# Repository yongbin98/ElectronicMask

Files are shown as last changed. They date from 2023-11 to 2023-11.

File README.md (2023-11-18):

# ElectronicMask
The code is for the assignment "Developing breathing-based vital signs detection models and control algorithms to improve sleep quality" <br>

# Sensors
`MCU` : STM32F765VI <br>
`Bluetooth` : E104-BT5005A <br>
`Pressure Sensor` : LPS22HHTR <br>
`Microphone` : SPH0645LM4H-1-8 <br>
`IMU Sensor` : LSM6DSMTR <br>
`PPG Sensor` : MAX86171 & SFH 7072 <br>
`EMG EOG EEG sensor` : ADS1299 <br>

# Developed ElectronicMask (Prototype)


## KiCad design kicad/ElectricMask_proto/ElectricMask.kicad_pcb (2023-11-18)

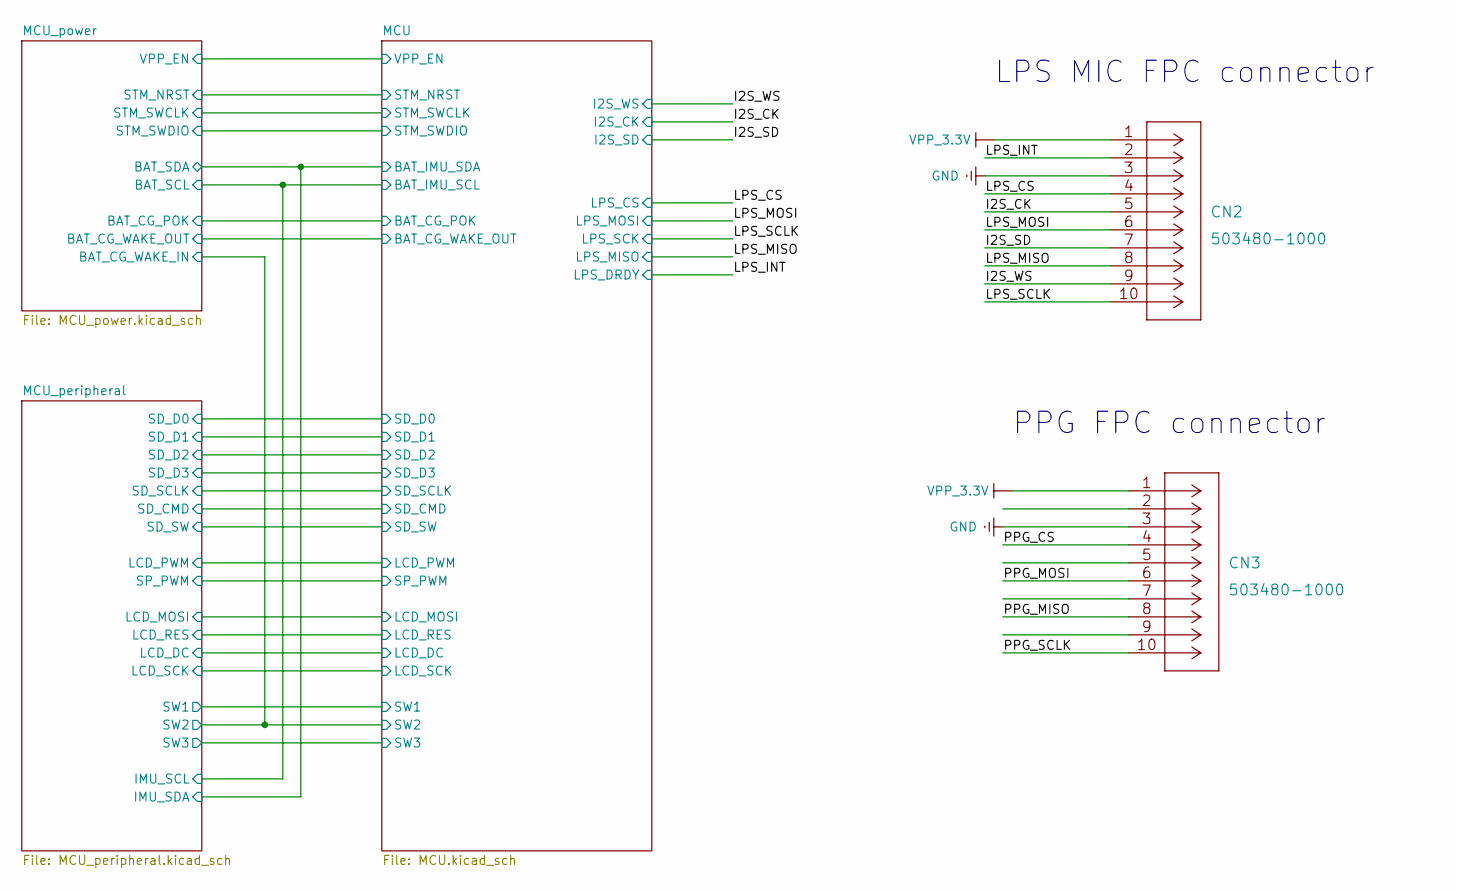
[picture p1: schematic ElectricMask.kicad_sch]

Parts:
CN2, CN3: 503480-1000

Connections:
/I2S_CK: CN2.5; also elsewhere on the board
/I2S_SD: CN2.7; also elsewhere on the board
/I2S_WS: CN2.9; also elsewhere on the board
/LPS_CS: CN2.4; also elsewhere on the board
/LPS_INT: CN2.2; also elsewhere on the board
/LPS_MISO: CN2.8; also elsewhere on the board
/LPS_MOSI: CN2.6; also elsewhere on the board
/LPS_SCLK: CN2.10; also elsewhere on the board

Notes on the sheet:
PPG FPC connector
LPS MIC FPC connector

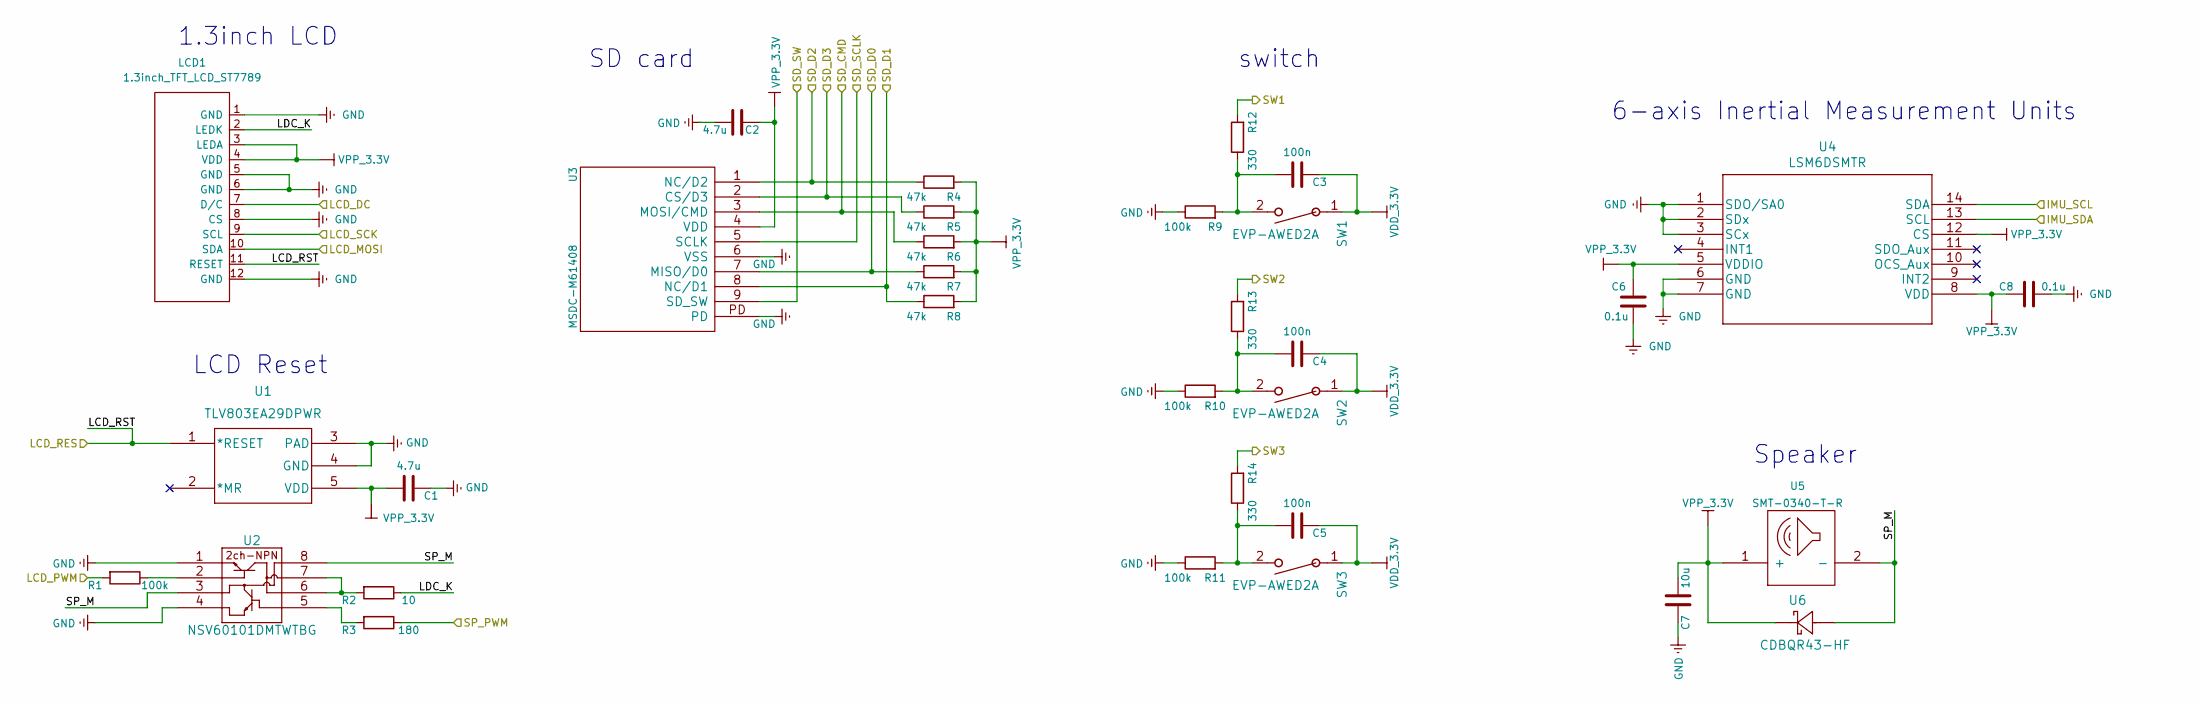
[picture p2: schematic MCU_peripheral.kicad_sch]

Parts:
C1, C2: 4.7u; UL_C_0402_1005Metric
C3, C4, C5: 100n; UL_C_0402_1005Metric
C6, C8: 0.1u; UL_C_0402_1005Metric
C7: 10u; UL_C_0402_1005Metric
LCD1: 1.3inch_TFT_LCD_ST7789
R1, R9, R10, R11: 100k; R_0402_1005Metric
R2: 10; R_0402_1005Metric
R3: 180; R_0402_1005Metric
R4, R5, R6, R7, R8: 47k; R_0402_1005Metric
R12, R13, R14: 330; R_0402_1005Metric
SW1, SW2, SW3: EVP-AWED2A
U1: TLV803EA29DPWR
U2: NSV60101DMTWTBG
U3: MSDC-M61408; MSDC-M61408(Micro_SD)
U4: LSM6DSMTR
U5: SMT-0340-T-R
U6: CDBQR43-HF

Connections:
/MCU/BAT_IMU_SCL: U4.14 (SDA); also elsewhere on the board
/MCU/BAT_IMU_SDA: U4.13 (SCL); also elsewhere on the board
/MCU/LCD_DC: LCD1.7 (D/C); also elsewhere on the board
/MCU/LCD_MOSI: LCD1.10 (SDA); also elsewhere on the board
/MCU/LCD_PWM: R1.2; also elsewhere on the board
/MCU/LCD_SCK: LCD1.9 (SCL); also elsewhere on the board
/MCU/SD_CMD: R6.1, U3.3 (MOSI/CMD); also elsewhere on the board
/MCU/SD_D0: R7.1, U3.7 (MISO/D0); also elsewhere on the board
/MCU/SD_D1: R8.1, U3.8 (NC/D1); also elsewhere on the board
/MCU/SD_D2: R4.1, U3.1 (NC/D2); also elsewhere on the board
/MCU/SD_D3: R5.1, U3.2 (CS/D3); also elsewhere on the board
/MCU/SD_SCLK: U3.5 (SCLK); also elsewhere on the board
/MCU/SD_SW: U3.9 (SD_SW); also elsewhere on the board
/MCU/SP_PWM: R3.1; also elsewhere on the board
/MCU/SW1: R12.2; also elsewhere on the board
/MCU/SW2: R13.2; also elsewhere on the board
/MCU/SW3: R14.2; also elsewhere on the board
/MCU_peripheral/LCD_RST: LCD1.11 (RESET), U1.1 (*RESET); also elsewhere on the board
/MCU_peripheral/LDC_K: LCD1.2 (LEDK), R2.1
/MCU_peripheral/SP_M: U2.3, U2.8, U5.2 (-), U6.2
unnamed: C3.2, R9.2, R12.1, SW1.2
unnamed: C4.2, R10.2, R13.1, SW2.2
unnamed: C5.2, R11.2, R14.1, SW3.2
unnamed: R1.1, U2.2
unnamed: R2.2, U2.6, U2.7
unnamed: R3.2, U2.5
VDD_3_3V: C3.1, C4.1, C5.1, SW1.1, SW2.1, SW3.1; also elsewhere on the board

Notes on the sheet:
Speaker
6-axis Inertial Measurement Units
LCD Reset
SD card
1.3inch LCD
switch

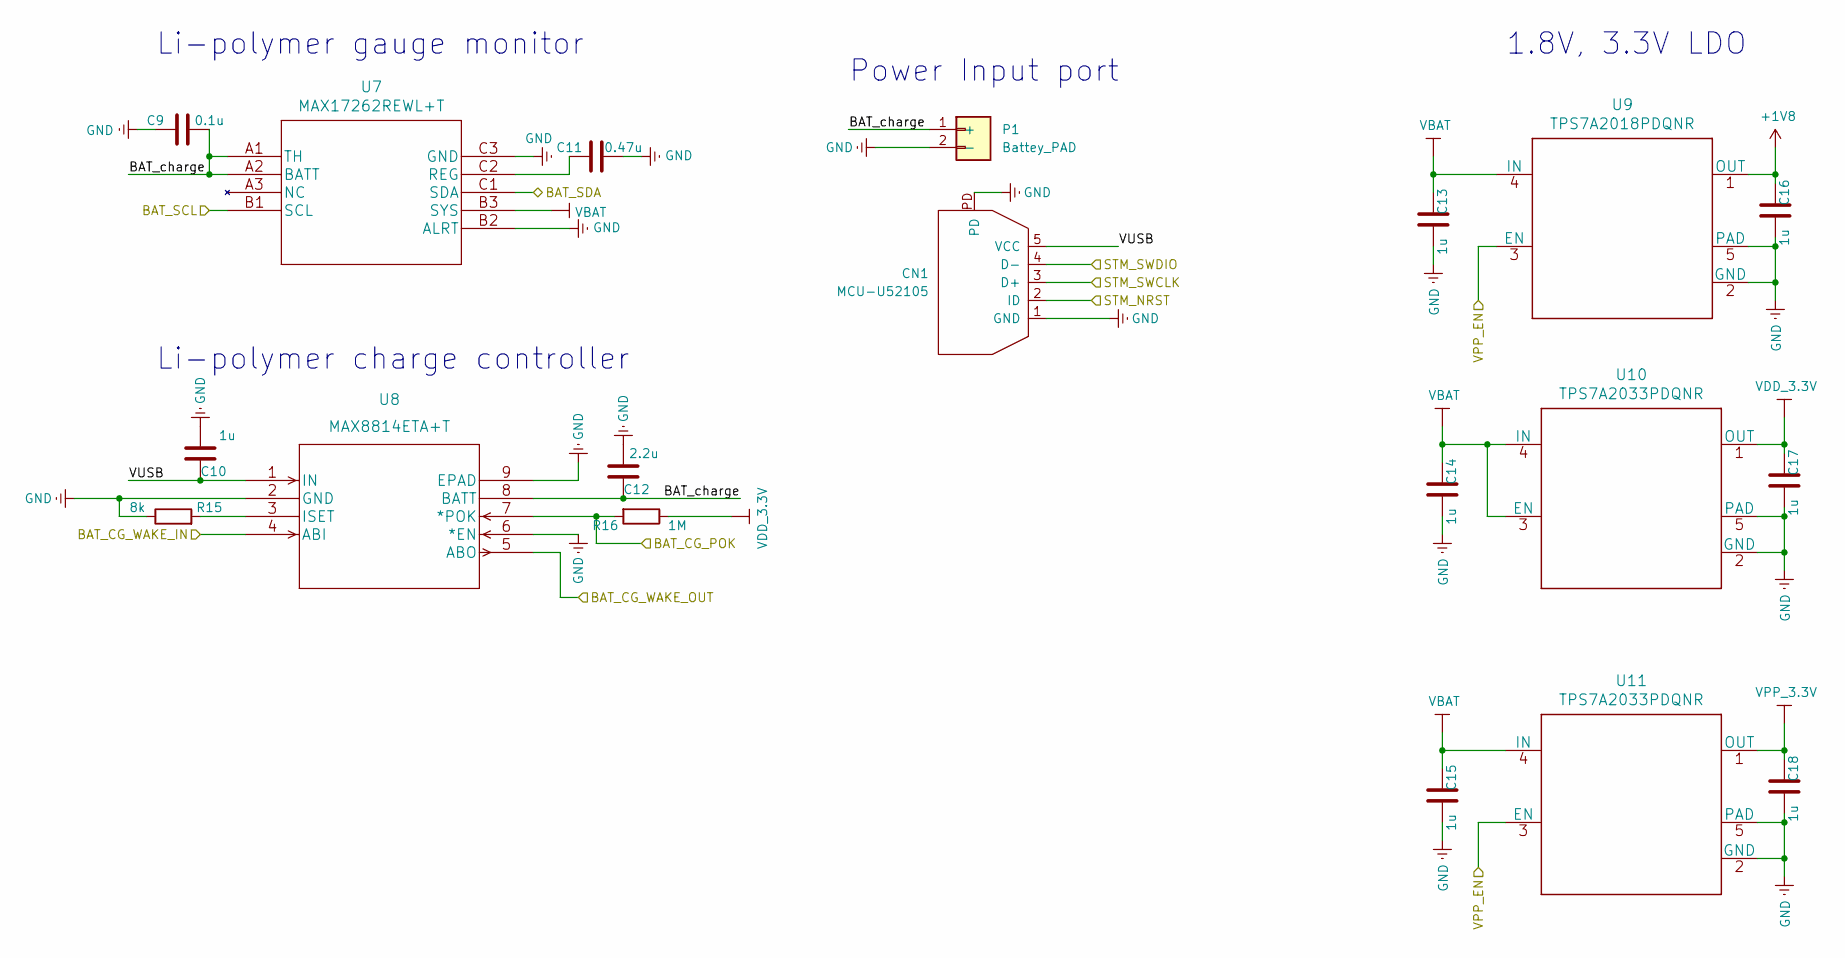
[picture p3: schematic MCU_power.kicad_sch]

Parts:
C9: 0.1u; UL_C_0402_1005Metric
C10, C13, C14, C15, C16, C17, C18: 1u; UL_C_0402_1005Metric
C11: 0.47u; UL_C_0402_1005Metric
C12: 2.2u; UL_C_0402_1005Metric
CN1: MCU-U52105
P1: Battey_PAD
R15: 8k; R_0402_1005Metric
R16: 1M; R_0402_1005Metric
U7: MAX17262REWL+T; MAX17262REWL&plus_T
U8: MAX8814ETA+T; MAX8814ETA&plus_T
U9: TPS7A2018PDQNR; X2SON-4PIN
U10, U11: TPS7A2033PDQNR; X2SON-4PIN

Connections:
+1V8: C16.2, U9.1 (OUT)
/MCU/BAT_CG_POK: R16.2, U8.7 (*POK); also elsewhere on the board
/MCU/BAT_CG_WAKE_OUT: U8.5 (ABO); also elsewhere on the board
/MCU/BAT_IMU_SCL: U7.B1 (SCL); also elsewhere on the board
/MCU/BAT_IMU_SDA: U7.C1 (SDA); also elsewhere on the board
/MCU/STM_NRST: CN1.2 (ID); also elsewhere on the board
/MCU/STM_SWCLK: CN1.3 (D+); also elsewhere on the board
/MCU/STM_SWDIO: CN1.4 (D-); also elsewhere on the board
/MCU/SW2: U8.4 (ABI); also elsewhere on the board
/MCU/VPP_EN: U9.3 (EN), U11.3 (EN); also elsewhere on the board
/MCU_power/BAT_charge: C9.2, C12.1, P1.1 (+), U7.A1 (TH), U7.A2 (BATT), U8.8 (BATT)
/MCU_power/VUSB: C10.1, CN1.5 (VCC), U8.1 (IN)
unnamed: C11.2, U7.C2 (REG)
unnamed: R15.2, U8.3 (ISET)
VBAT: C13.2, C14.2, C15.2, U7.B3 (SYS), U9.4 (IN), U10.3 (EN), U10.4 (IN), U11.4 (IN)
VDD_3_3V: C17.2, R16.1, U10.1 (OUT); also elsewhere on the board

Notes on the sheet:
Power Input port
Li-polymer gauge monitor
1.8V, 3.3V LDO
Li-polymer charge controller

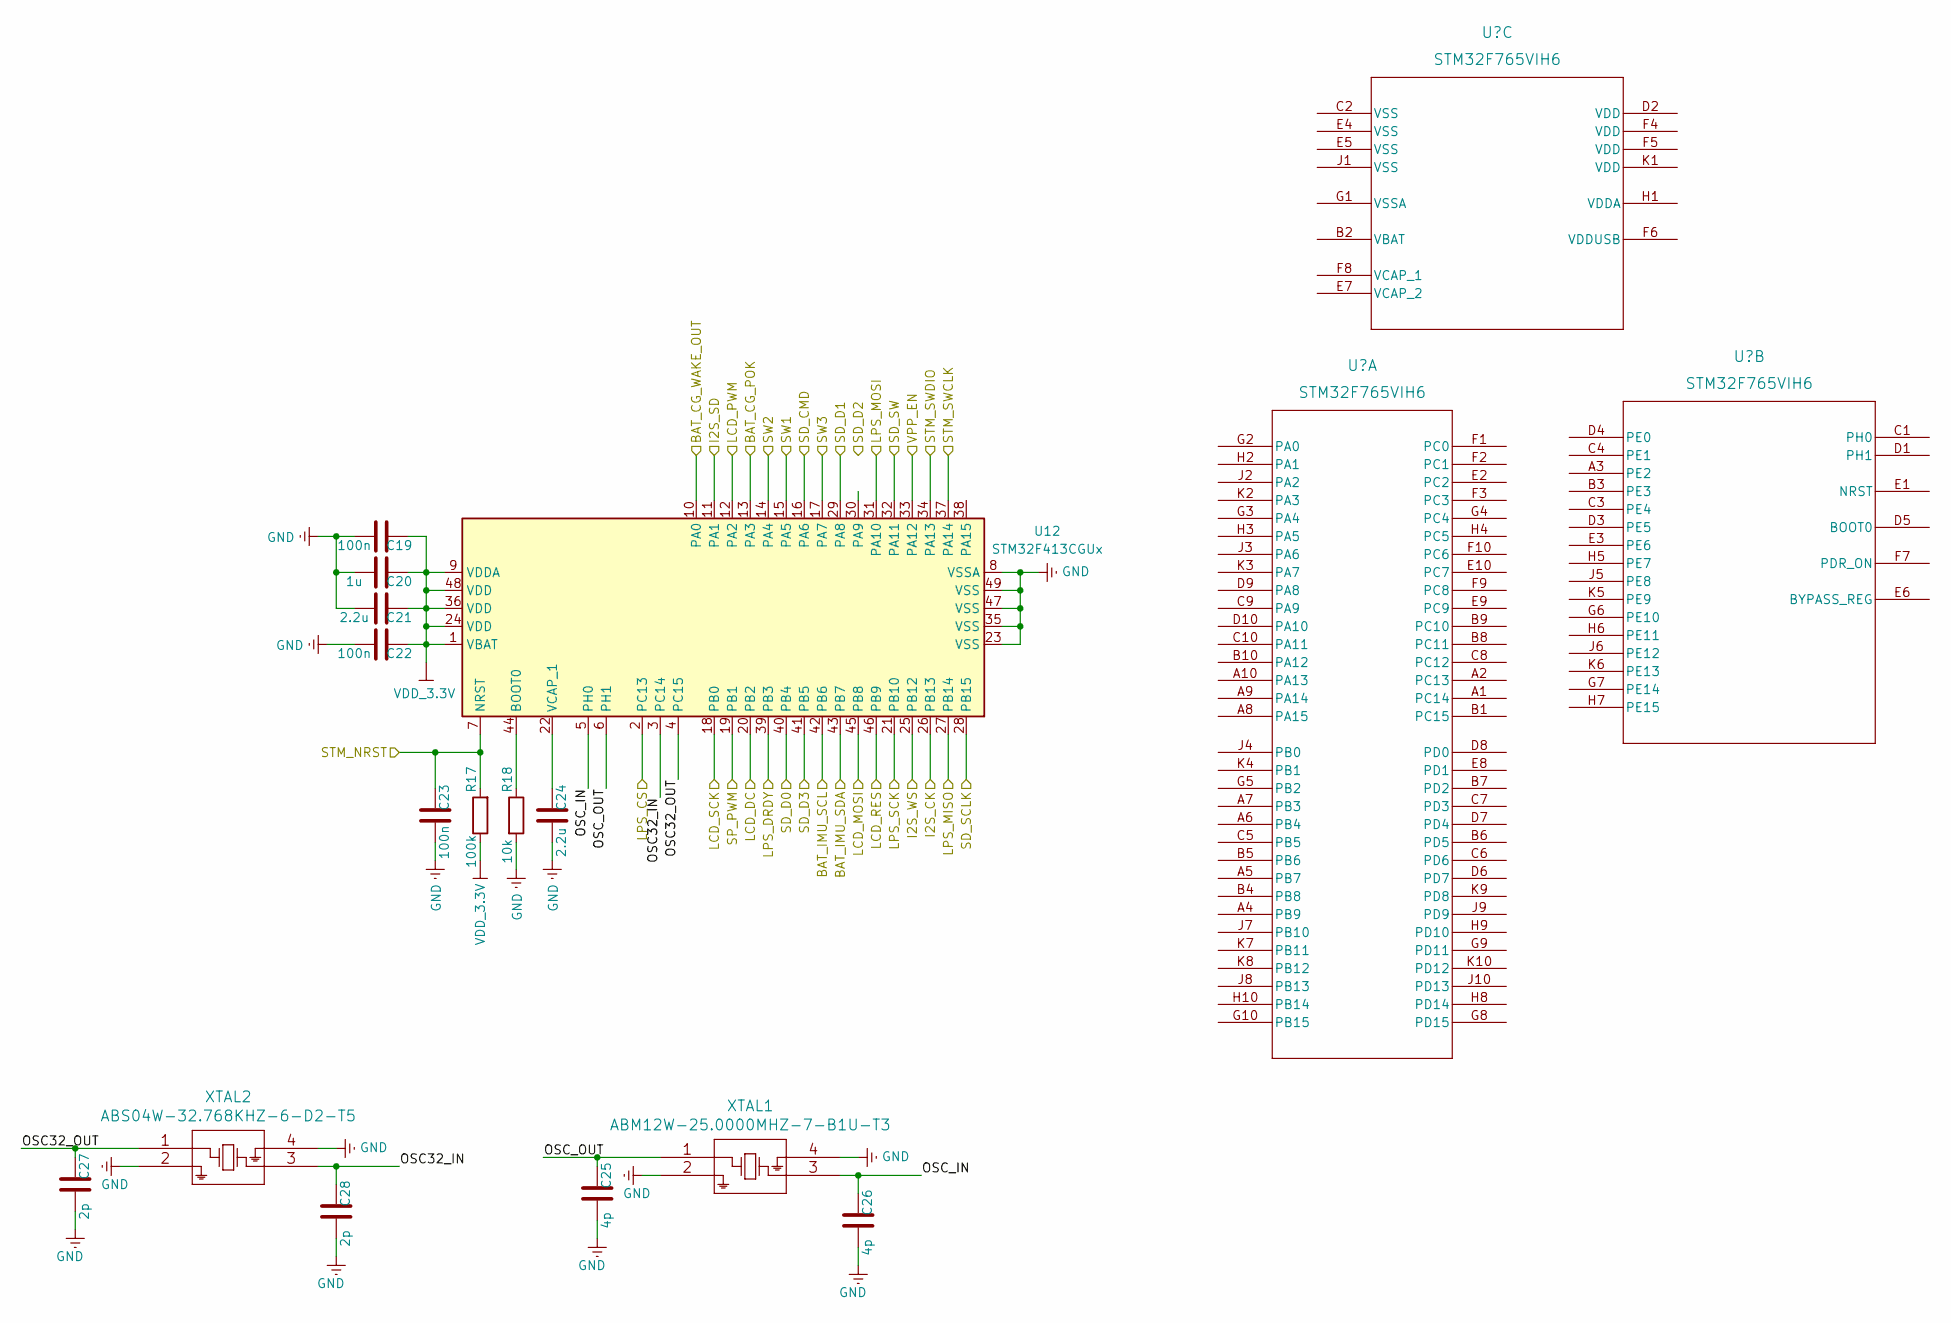
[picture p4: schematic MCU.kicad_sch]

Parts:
C19, C22, C23: 100n; UL_C_0402_1005Metric
C20: 1u; UL_C_0402_1005Metric
C21, C24: 2.2u; UL_C_0402_1005Metric
C25, C26: 4p; UL_C_0402_1005Metric
C27, C28: 2p; UL_C_0402_1005Metric
R17: 100k; R_0402_1005Metric
R18: 10k; R_0402_1005Metric
U12: STM32F413CGUx; QFN-48-1EP_7x7mm_P0.5mm_EP5.6x5.6mm
XTAL1: ABM12W-25.0000MHZ-7-B1U-T3; ABM12W
XTAL2: ABS04W-32.768KHZ-6-D2-T5; ABS04W

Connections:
/I2S_CK: U12.26 (PB13); also elsewhere on the board
/I2S_SD: U12.11 (PA1); also elsewhere on the board
/I2S_WS: U12.25 (PB12); also elsewhere on the board
/LPS_CS: U12.2 (PC13); also elsewhere on the board
/LPS_INT: U12.39 (PB3); also elsewhere on the board
/LPS_MISO: U12.27 (PB14); also elsewhere on the board
/LPS_MOSI: U12.31 (PA10); also elsewhere on the board
/LPS_SCLK: U12.21 (PB10); also elsewhere on the board
/MCU/BAT_CG_POK: U12.13 (PA3); also elsewhere on the board
/MCU/BAT_CG_WAKE_OUT: U12.10 (PA0); also elsewhere on the board
/MCU/BAT_IMU_SCL: U12.42 (PB6); also elsewhere on the board
/MCU/BAT_IMU_SDA: U12.43 (PB7); also elsewhere on the board
/MCU/LCD_DC: U12.20 (PB2); also elsewhere on the board
/MCU/LCD_MOSI: U12.45 (PB8); also elsewhere on the board
/MCU/LCD_PWM: U12.12 (PA2); also elsewhere on the board
/MCU/LCD_SCK: U12.18 (PB0); also elsewhere on the board
/MCU/OSC32_IN: C28.2, U12.3 (PC14), XTAL2.3
/MCU/OSC32_OUT: C27.2, U12.4 (PC15), XTAL2.1
/MCU/OSC_IN: C26.2, U12.5 (PH0), XTAL1.3
/MCU/OSC_OUT: C25.2, U12.6 (PH1), XTAL1.1
/MCU/SD_CMD: U12.16 (PA6); also elsewhere on the board
/MCU/SD_D0: U12.40 (PB4); also elsewhere on the board
/MCU/SD_D1: U12.29 (PA8); also elsewhere on the board
/MCU/SD_D2: U12.30 (PA9); also elsewhere on the board
/MCU/SD_D3: U12.41 (PB5); also elsewhere on the board
/MCU/SD_SCLK: U12.28 (PB15); also elsewhere on the board
/MCU/SD_SW: U12.32 (PA11); also elsewhere on the board
/MCU/SP_PWM: U12.19 (PB1); also elsewhere on the board
/MCU/STM_NRST: C23.2, R17.2, U12.7 (NRST); also elsewhere on the board
/MCU/STM_SWCLK: U12.37 (PA14); also elsewhere on the board
/MCU/STM_SWDIO: U12.34 (PA13); also elsewhere on the board
/MCU/SW1: U12.15 (PA5); also elsewhere on the board
/MCU/SW2: U12.14 (PA4); also elsewhere on the board
/MCU/SW3: U12.17 (PA7); also elsewhere on the board
/MCU/VPP_EN: U12.33 (PA12); also elsewhere on the board
/MCU_peripheral/LCD_RST: U12.46 (PB9); also elsewhere on the board
unnamed: C24.2, U12.22 (VCAP_1)
unnamed: R18.1, U12.44 (BOOT0)
VDD_3_3V: C19.2, C20.2, C21.2, C22.2, R17.1, U12.1 (VBAT), U12.9 (VDDA), U12.24 (VDD), U12.36 (VDD), U12.48 (VDD); also elsewhere on the board

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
Board: 2 copper layers, 67 parts (0 on the bottom side), 57 nets, no tracks yet.

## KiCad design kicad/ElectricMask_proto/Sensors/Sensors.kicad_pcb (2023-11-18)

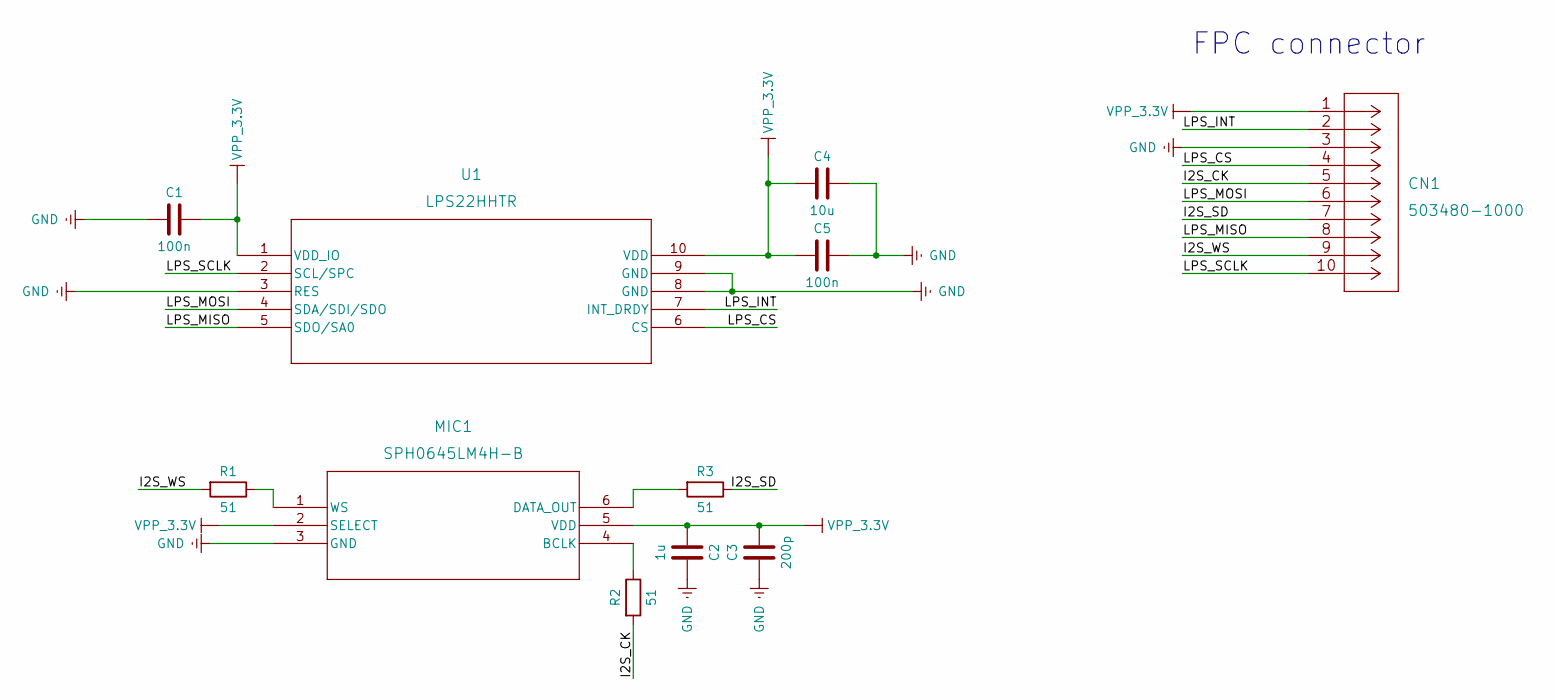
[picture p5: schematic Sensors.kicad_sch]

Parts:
C1, C5: 100n; UL_C_0402_1005Metric
C2: 1u; UL_C_0402_1005Metric
C3: 200p; UL_C_0402_1005Metric
C4: 10u; UL_C_0402_1005Metric
CN1: 503480-1000
MIC1: SPH0645LM4H-B; SPH0645LM4H-B_KNO
R1, R2, R3: 51; R_0402_1005Metric
U1: LPS22HHTR; HLGA-10L_2X2X0P73_STM

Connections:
/I2S_CK: CN1.5, R2.2
/I2S_SD: CN1.7, R3.1
/I2S_WS: CN1.9, R1.2
/LPS_CS: CN1.4, U1.6 (CS)
/LPS_INT: CN1.2, U1.7 (INT_DRDY)
/LPS_MISO: CN1.8, U1.5 (SDO/SA0)
/LPS_MOSI: CN1.6, U1.4 (SDA/SDI/SDO)
/LPS_SCLK: CN1.10, U1.2 (SCL/SPC)
unnamed: MIC1.1 (WS), R1.1
unnamed: MIC1.4 (BCLK), R2.1
unnamed: MIC1.6 (DATA_OUT), R3.2
U_GND: C1.1, C2.2, C3.1, C4.2, C5.2, CN1.3, CN1.11, CN1.12, MIC1.3 (GND), U1.3 (RES), U1.8 (GND), U1.9 (GND)
VDD: C1.2, C2.1, C3.2, C4.1, C5.1, CN1.1, MIC1.2 (SELECT), MIC1.5 (VDD), U1.1 (VDD_IO), U1.10 (VDD)

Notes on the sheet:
FPC connector

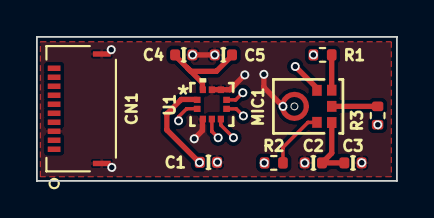
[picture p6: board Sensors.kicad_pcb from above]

Board: 4 copper layers, 20.0 x 8.0 mm, 11 parts (0 on the bottom side), 13 nets.

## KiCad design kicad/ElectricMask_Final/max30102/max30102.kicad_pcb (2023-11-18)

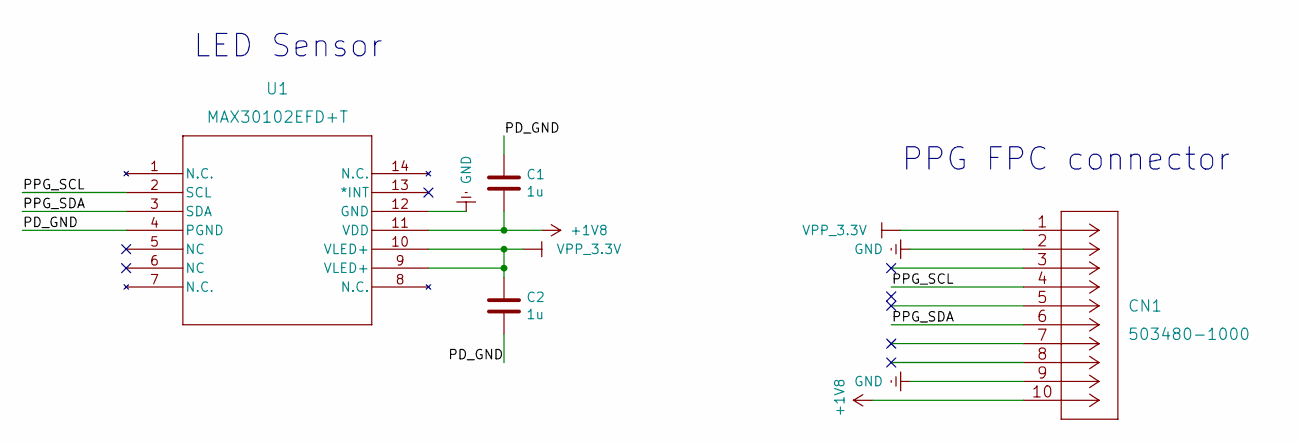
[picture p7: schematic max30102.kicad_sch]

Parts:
C1, C2: 1u; UL_C_0402_1005Metric
CN1: 503480-1000
U1: MAX30102EFD+T; MAX30102

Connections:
+1V8: C1.2, CN1.10, U1.11 (VDD)
/PD_GND: C1.1, C2.2, U1.4 (PGND)
/PPG_SCL: CN1.4, U1.2 (SCL)
/PPG_SDA: CN1.6, U1.3 (SDA)
U_GND: CN1.2, CN1.9, CN1.11, CN1.12, U1.12 (GND)
VPP_3_3V: C2.1, CN1.1, U1.9 (VLED+), U1.10 (VLED+)

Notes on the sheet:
LED Sensor
PPG FPC connector

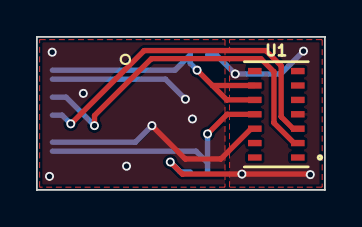
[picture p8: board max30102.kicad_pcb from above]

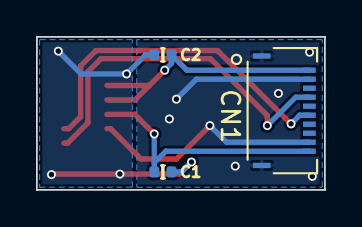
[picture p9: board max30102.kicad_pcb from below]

Board: 2 copper layers, 16.0 x 8.5 mm, 4 parts (3 on the bottom side), 6 nets.

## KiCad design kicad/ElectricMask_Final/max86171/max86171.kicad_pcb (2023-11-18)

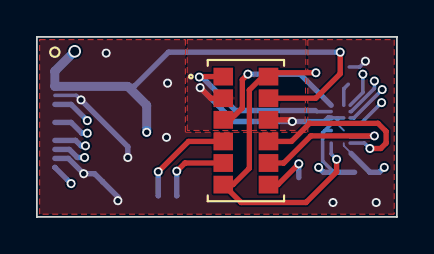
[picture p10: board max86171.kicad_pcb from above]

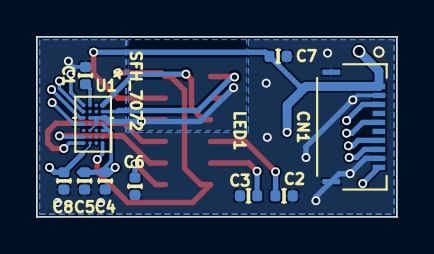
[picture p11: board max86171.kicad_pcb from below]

Board: 4 copper layers, 20.0 x 10.0 mm, 11 parts (10 on the bottom side), 13 nets.

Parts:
C1: 1u; UL_C_0402_1005Metric
C2, C3, C6, C7: 22u; UL_C_0402_1005Metric
C4, C8: 10u; UL_C_0402_1005Metric
C5: 0.1u; UL_C_0402_1005Metric
CN1: 503480-1000
LED1: SFH_7072; SFH 7072
U1: MAX86171ENI+; MAX86171ENI&plus_

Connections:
+1V8: C4.1, C5.1, CN1.10, U1.D3 (VDD_ANA), U1.D4 (VDD_DIG)
/LED3_DRV: LED1.9, U1.A1 (LED3_DRV)
/LED4_DRV: LED1.6, LED1.12, U1.D1 (LED4_DRV)
/LED9_DRV: LED1.8, U1.A2 (LED9_DRV)
/PD1_IN: LED1.3, U1.D7 (PD1_IN)
/PD2_IN: LED1.1, U1.D6 (PD2_IN)
/PPG_CS: CN1.3, U1.A7 (CSB/ADDR)
/PPG_MISO: CN1.7, U1.A5 (SDO)
/PPG_MOSI: CN1.5, U1.A6 (SDI/SDA)
/PPG_SCLK: CN1.8, U1.A4 (SCLK/SCL)
unnamed: C1.1, U1.B7 (VREF)
U_GND: C1.2, C2.2, C3.2, C4.2, C5.2, C6.2, C7.2, C8.2, CN1.2, CN1.9, CN1.11, CN1.12, LED1.2, LED1.10, U1.B3 (PGND), U1.B5 (TRIG), U1.C4 (I2C_SEL), U1.C5 (GND), U1.D5 (PD_GND)
VPP_3_3V: C2.1, C3.1, C6.1, C7.1, C8.1, CN1.1, LED1.4, LED1.5, LED1.7, LED1.11, U1.B1 (VLED)

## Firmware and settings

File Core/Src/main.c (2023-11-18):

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
/* Includes ------------------------------------------------------------------*/
#include "main.h"
#include "fatfs.h"

/* USER CODE BEGIN Includes */
#include "LPS22HH.h"
#include "fifo.h"
#include "LSM6DS.h"
#include "lcdscreen.h"

/* USER CODE END Includes */

/* USER CODE BEGIN PD */

bool read_cnt = false;

/* USER CODE END PD */

 I2C_HandleTypeDef hi2c1;

I2S_HandleTypeDef hi2s4;
DMA_HandleTypeDef hdma_spi4_rx;

IWDG_HandleTypeDef hiwdg;

SD_HandleTypeDef hsd;
DMA_HandleTypeDef hdma_sdio_tx;
DMA_HandleTypeDef hdma_sdio_rx;

SPI_HandleTypeDef hspi2;
SPI_HandleTypeDef hspi5;
DMA_HandleTypeDef hdma_spi2_rx;
DMA_HandleTypeDef hdma_spi2_tx;
DMA_HandleTypeDef hdma_spi5_rx;
DMA_HandleTypeDef hdma_spi5_tx;

TIM_HandleTypeDef htim6;
TIM_HandleTypeDef htim7;
TIM_HandleTypeDef htim9;

/* USER CODE BEGIN PV */

// LPS
float dataPressure;
float dataTemperature;
float dataAltitude;
uintmax_t timeflag = 0;
bool left_btn = false;
bool ok_btn = false;
bool right_btn = false;
bool btn_flag = false;
bool save_flag = false;
uint8_t nowScreen = 0;

// MIC
uint8_t half_i2s, full_i2s;
int16_t sample_i2s;
int16_t audioBuffer[WAV_WRITE_SAMPLE_COUNT];

//IMU
LSM6DS_AccelSetting LSM6DSM_IMUSetting={
	1,					//accelEnabled
	50,				//accelBandWidth
	8,					//accelRange
	52,			//accelSampleRate
	1,					//gyroEnabled
	500,			//gyroRange
	52,			//gyroSampleRate
	1,					//tempEnabled
};
int16_t I2C_Polling_buffer[6] = {0};

/* USER CODE END PV */

void SystemClock_Config(void);
static void MX_GPIO_Init(void);
static void MX_DMA_Init(void);
static void MX_I2C1_Init(void);
static void MX_I2S4_Init(void);
static void MX_SDIO_SD_Init(void);
static void MX_SPI2_Init(void);
static void MX_SPI5_Init(void);
static void MX_TIM6_Init(void);
static void MX_TIM9_Init(void);
static void MX_IWDG_Init(void);
static void MX_TIM7_Init(void);
/* USER CODE BEGIN PFP */
void Set_StandbyMod(void);
void UF_speaker_ON(void);
void UF_speaker_OFF(void);
void HAL_GPIO_EXTI_Callback(uint16_t GPIO_Pin);
/* USER CODE END PFP */

/**
  * @brief  The application entry point.
  * @retval int
  */
int main(void)
{
  /* MCU Configuration--------------------------------------------------------*/

  /* Reset of all peripherals, Initializes the Flash interface and the Systick. */
  HAL_Init();

  /* Configure the system clock */
  SystemClock_Config();

  /* USER CODE BEGIN SysInit */
	MX_IWDG_Init();
	if(__HAL_RCC_GET_FLAG(RCC_FLAG_IWDGRST) == SET){
		Set_StandbyMod();
	}
  /* USER CODE END SysInit */

  /* Initialize all configured peripherals */
  MX_GPIO_Init();
  MX_DMA_Init();
  MX_I2C1_Init();
  MX_I2S4_Init();
  MX_SDIO_SD_Init();
  MX_SPI2_Init();
  MX_SPI5_Init();
  MX_TIM6_Init();
  MX_TIM9_Init();
  MX_FATFS_Init();
  MX_IWDG_Init();
  MX_TIM7_Init();
  /* USER CODE BEGIN 2 */
	
	// VPP EN
	HAL_GPIO_WritePin(VPP_EN_GPIO_Port,VPP_EN_Pin,GPIO_PIN_SET);
	if(!HAL_GPIO_ReadPin(BAT_CG_POK_GPIO_Port,BAT_CG_POK_Pin))
		Set_StandbyMod();
  HAL_Delay(100);
//	UF_speaker_ON();
	
	// WATCH dog
	__HAL_DBGMCU_FREEZE_IWDG();
	
	/* Battery Monitoring */
	MAX17262_init();
		
	/* SD Init */
	HAL_IWDG_Refresh(&hiwdg);
	if(sd_init()){
		Error_Handler();
	}
	
	// LCD init
	screen_init(&htim9);
	main_screen(false,false,false,0,0);
	
	/* LPS setup */
	LPS22HH_setup();
	
	// MIC init	
	HAL_I2S_Receive_DMA(&hi2s4,(uint16_t *)audioBuffer,sizeof(audioBuffer)/2);	
	
//	//IMU setup
//	LSM6DS_Reset();
//	LSM6DS_GetBeing_polling(&LSM6DSM_IMUSetting);	//자이로 가속도 센서 활성화
	
	// interrupt start	
	HAL_TIM_Base_Start_IT(&htim6);
	HAL_TIM_Base_Start_IT(&htim7);
//	UF_speaker_OFF();
  /* USER CODE END 2 */

  /* Infinite loop */
  /* USER CODE BEGIN WHILE */
  while (1)
  {
		HAL_IWDG_Refresh(&hiwdg);
			
		if(nowScreen == 0){ // main screen
			if(timeflag % 100 == 0){ //0.1sec 
				dataPressure = LPS22HH_readPressure();	
				main_screen(left_btn,ok_btn,right_btn,(uint16_t)sample_i2s,dataPressure);
			}
			if(left_btn){
				nowScreen = 1;
				reset_screen();
			}
			else if(right_btn){
				Set_StandbyMod();
			}
									
		}else if (nowScreen == 1){ // menu screen	
			if(timeflag % 100 == 0) // 0.1sec
				menu_screen(left_btn,ok_btn,right_btn,0);
			
			if(left_btn){
				nowScreen = 0;
				reset_screen();				
			}else if(ok_btn){
				timeflag = 0;
				reset_screen();
				general_screen(false,false,false);
				nowScreen = 2; 
				if(start_recording_i2s(hi2s4.Init.AudioFreq))
					Error_Handler();				
				if(start_recording_lps())
					Error_Handler();		
			}else if(right_btn){
				reset_screen();
				menu_screen(left_btn,ok_btn,right_btn,0);
			}
		}
		else if(nowScreen == 2){
			if(timeflag % 1000 == 0 && half_i2s == 0 && full_i2s == 0 && read_cnt == false)
				fifo_screen(left_btn,ok_btn,right_btn,timeflag,dataPressure);
						
			if(read_cnt){
				dataPressure = LPS22HH_readPressure();
				dataTemperature = LPS22HH_readTemperature();
				dataAltitude = LPS22HH_calAltitude(dataPressure,dataTemperature);
				fifo_lps(dataTemperature,dataPressure,dataAltitude,timeflag);
				
				read_cnt = false;
			}
			if(half_i2s == 1){
				fifo_i2s(((uint8_t *)audioBuffer), WAV_WRITE_SAMPLE_COUNT);
				half_i2s = 0;
			}			
			if(full_i2s == 1){
				fifo_i2s((uint8_t *)audioBuffer + WAV_WRITE_SAMPLE_COUNT, WAV_WRITE_SAMPLE_COUNT);
				full_i2s = 0;
			}
			if(left_btn){
				stop_recording_i2s();
				stop_recording_lps();
				nowScreen = 0;
				reset_screen();
			}
			if(save_flag){ // 30min after
				stop_recording_i2s();
				stop_recording_lps();
				reset_screen();
				general_screen(false,false,false);
				save_flag = false;
				if(start_recording_lps())
					Error_Handler();
				if(start_recording_i2s(hi2s4.Init.AudioFreq))
					Error_Handler();				
			}
		}
		btn_flag = false; left_btn = false; right_btn = false; ok_btn = false; 	
		
    /* USER CODE END WHILE */

    /* USER CODE BEGIN 3 */
  }
  /* USER CODE END 3 */
}

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
/* USER CODE BEGIN 4 */

void Set_StandbyMod(void) {
	// turn off the watch
	while(HAL_GPIO_ReadPin(SW2_GPIO_Port, SW2_Pin));
	HAL_Delay(1000);
//	HAL_GPIO_WritePin(BLE_MOD_GPIO_Port, BLE_MOD_Pin, GPIO_PIN_RESET);
//  printf("AT+SLEEP");
//   
//  HAL_GPIO_WritePin(BLE_TX_GPIO_Port, BLE_TX_Pin, GPIO_PIN_RESET);
//  HAL_GPIO_WritePin(BLE_RX_GPIO_Port, BLE_RX_Pin, GPIO_PIN_RESET);

	HAL_IWDG_Refresh(&hiwdg);
		
	//사용 된 모든 웨이크 업 소스를 비활성화
	HAL_PWR_DisableWakeUpPin(PWR_WAKEUP_PIN1);
	
	// ALL FLAG RESET
  __HAL_PWR_CLEAR_FLAG(PWR_FLAG_WU);
	
	//사용 된 모든 웨이크 업 소스를 다시 사용 가능하게 설정 
	HAL_PWR_EnableWakeUpPin(PWR_WAKEUP_PIN1);
	
	if (HAL_IWDG_Init(&hiwdg) != HAL_OK)
	{
		Error_Handler();
	}
	__HAL_RCC_CLEAR_RESET_FLAGS();
	
	HAL_GPIO_WritePin(VPP_EN_GPIO_Port,VPP_EN_Pin,GPIO_PIN_RESET);
	
	//스탠바이모드 진입
	HAL_PWR_EnterSTANDBYMode();
}
	

void UF_speaker_ON(void) {
//	// speaker sound on
//	HAL_TIM_PWM_Start(&htim3, TIM_CHANNEL_4);
	TIM3->ARR=250;
	//TIM2->CCR2=(int)(325/2);
	TIM3->CCR4=(int)(200/2);
}

void UF_speaker_OFF(void) {
	// speaker sound off
	TIM3->CCR4=0;
//	HAL_TIM_PWM_Stop(&htim3, TIM_CHANNEL_4);
}	

void HAL_GPIO_EXTI_Callback(uint16_t GPIO_Pin)
{
	if (GPIO_Pin == GPIO_PIN_5)
	{
		left_btn = true;
	}
	
	else if (GPIO_Pin == GPIO_PIN_4)
	{
		ok_btn = true;
	}
	
	else if (GPIO_Pin == GPIO_PIN_7)
	{
		right_btn = true;
	}
	btn_flag = true;
}

void HAL_I2S_RxCpltCallback(I2S_HandleTypeDef *hi2s)
{
	full_i2s = 1;
}

void HAL_I2S_RxHalfCpltCallback(I2S_HandleTypeDef *hi2s)
{
	sample_i2s = audioBuffer[0];
	half_i2s = 1;
}

/* USER CODE END 4 */

/**
  * @brief  Period elapsed callback in non blocking mode
  * @note   This function is called  when TIM1 interrupt took place, inside
  * HAL_TIM_IRQHandler(). It makes a direct call to HAL_IncTick() to increment
  * a global variable "uwTick" used as application time base.
  * @param  htim : TIM handle
  * @retval None
  */
void HAL_TIM_PeriodElapsedCallback(TIM_HandleTypeDef *htim)
{
  /* USER CODE BEGIN Callback 0 */

	if (htim->Instance == TIM6){ // 1000hz
		timeflag++;
		if(timeflag % 600000 == 0){
			save_flag = true;
		}
	}

	if (htim->Instance == TIM7){ // 200hz
		read_cnt = true;
	}
	
  /* USER CODE END Callback 0 */
  if (htim->Instance == TIM1) {
    HAL_IncTick();
  }
}

/**
  * @brief  This function is executed in case of error occurrence.
  * @retval None
  */
void Error_Handler(void)
{
  /* USER CODE BEGIN Error_Handler_Debug */
  /* User can add his own implementation to report the HAL error return state */
  __disable_irq();
  while (1)
  {
  }
  /* USER CODE END Error_Handler_Debug */
}

#ifdef  USE_FULL_ASSERT
/**
  * @brief  Reports the name of the source file and the source line number
  *         where the assert_param error has occurred.
  * @param  file: pointer to the source file name
  * @param  line: assert_param error line source number
  * @retval None
  */
void assert_failed(uint8_t *file, uint32_t line)
{
  /* USER CODE BEGIN 6 */
  /* User can add his own implementation to report the file name and line number,
     ex: printf("Wrong parameters value: file %s on line %d\r\n", file, line) */
  /* USER CODE END 6 */
}
#endif /* USE_FULL_ASSERT */

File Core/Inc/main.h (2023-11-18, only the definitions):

#define LPS_CS_Pin GPIO_PIN_14
#define LPS_CS_GPIO_Port GPIOC
#define BAT_CG_POK_Pin GPIO_PIN_15
#define BAT_CG_POK_GPIO_Port GPIOC
#define MIC_SD_Pin GPIO_PIN_1
#define MIC_SD_GPIO_Port GPIOA
#define LCD_PWM_Pin GPIO_PIN_2
#define LCD_PWM_GPIO_Port GPIOA
#define BLE_MOD_Pin GPIO_PIN_3
#define BLE_MOD_GPIO_Port GPIOA
#define SW2_Pin GPIO_PIN_4
#define SW2_GPIO_Port GPIOA
#define SW2_EXTI_IRQn EXTI4_IRQn
#define SW1_Pin GPIO_PIN_5
#define SW1_GPIO_Port GPIOA
#define SW1_EXTI_IRQn EXTI9_5_IRQn
#define SD_CMD_Pin GPIO_PIN_6
#define SD_CMD_GPIO_Port GPIOA
#define SW3_Pin GPIO_PIN_7
#define SW3_GPIO_Port GPIOA
#define SW3_EXTI_IRQn EXTI9_5_IRQn
#define LCD_SCK_Pin GPIO_PIN_0
#define LCD_SCK_GPIO_Port GPIOB
#define SP_PWM_Pin GPIO_PIN_1
#define SP_PWM_GPIO_Port GPIOB
#define LCD_DC_Pin GPIO_PIN_2
#define LCD_DC_GPIO_Port GPIOB
#define LPS_SCK_Pin GPIO_PIN_10
#define LPS_SCK_GPIO_Port GPIOB
#define MIC_WS_Pin GPIO_PIN_12
#define MIC_WS_GPIO_Port GPIOB
#define MIC_CK_Pin GPIO_PIN_13
#define MIC_CK_GPIO_Port GPIOB
#define LPS_MISO_Pin GPIO_PIN_14
#define LPS_MISO_GPIO_Port GPIOB
#define SD_CLK_Pin GPIO_PIN_15
#define SD_CLK_GPIO_Port GPIOB
#define SD_D1_Pin GPIO_PIN_8
#define SD_D1_GPIO_Port GPIOA
#define SD_D2_Pin GPIO_PIN_9
#define SD_D2_GPIO_Port GPIOA
#define LPS_MOSI_Pin GPIO_PIN_10
#define LPS_MOSI_GPIO_Port GPIOA
#define SD_SW_Pin GPIO_PIN_11
#define SD_SW_GPIO_Port GPIOA
#define VPP_EN_Pin GPIO_PIN_12
#define VPP_EN_GPIO_Port GPIOA
#define SD_D0_Pin GPIO_PIN_4
#define SD_D0_GPIO_Port GPIOB
#define SD_D3_Pin GPIO_PIN_5
#define SD_D3_GPIO_Port GPIOB
#define BAT_IMU_SCL_Pin GPIO_PIN_6
#define BAT_IMU_SCL_GPIO_Port GPIOB
#define BAT_IMU_SDA_Pin GPIO_PIN_7
#define BAT_IMU_SDA_GPIO_Port GPIOB
#define LCD_MOSI_Pin GPIO_PIN_8
#define LCD_MOSI_GPIO_Port GPIOB
#define LCD_RES_Pin GPIO_PIN_9
#define LCD_RES_GPIO_Port GPIOB

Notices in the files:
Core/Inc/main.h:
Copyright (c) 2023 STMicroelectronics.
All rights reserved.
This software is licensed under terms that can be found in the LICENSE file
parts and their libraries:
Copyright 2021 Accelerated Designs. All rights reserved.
